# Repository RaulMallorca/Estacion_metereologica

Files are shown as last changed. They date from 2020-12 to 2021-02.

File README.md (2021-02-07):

# # Hoja de ruta - Estación metereológica con NodeMcu.

_Modesto proyecto para afianzar conocimientos adquiridos en varios ámbitos._
_Este proyecto está basado en la colaboración de todas esas personas que comparten desisteresadamente sus trabajos. Está modificado para conseguir lo deseado._
_En algun lugar de este readme.me intentaré añadir todos los enlaces, gracias a los cuales, espero conseguir realizar la estación meteorológica._

Descripción del proyecto
_La estación medirá la temperatura, humedad, señal RSSI wifi, tanto interior como exterior, presión, rayos UV-A y UV-B, velocidad y dirección del viento y lluvia. Los datos se visualizarán en un dashboard creado 
en la plataforma de gestión de datos Thinger.io. Además con otro NodeMCU donde se obtendrán los datos de temperatura, humedad y señal RSSI wifi, interior, se mostrarán en una pantalla Nextion de 7".

## Material necesario 🚀

_El material utilizado se puede modificar pero se tendrá que hacer lo propio con el código._

**NodeMCU**

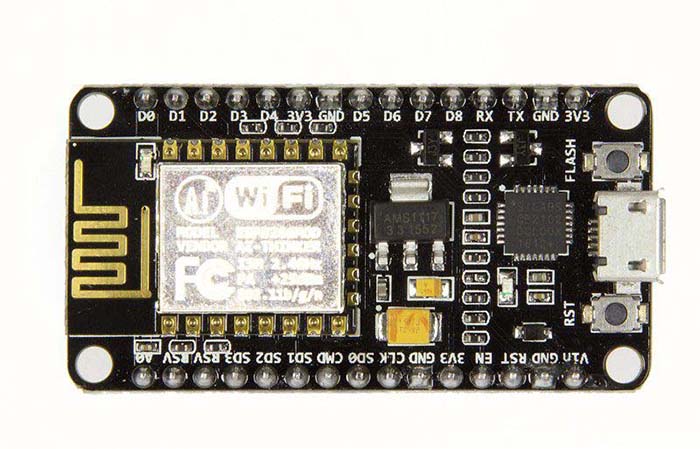
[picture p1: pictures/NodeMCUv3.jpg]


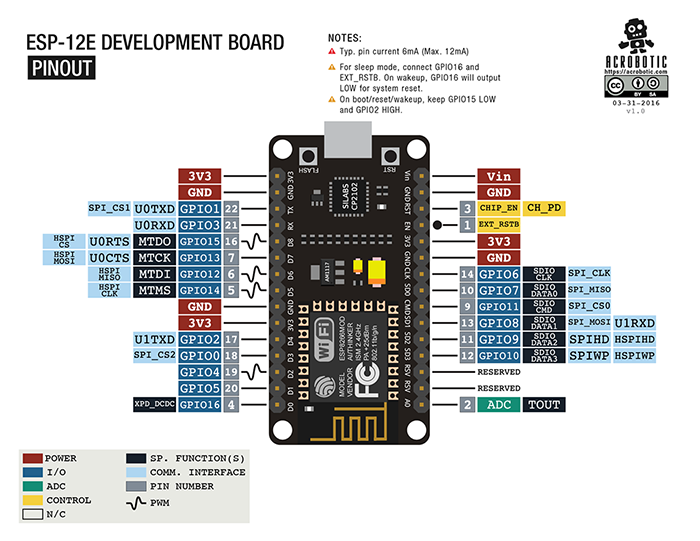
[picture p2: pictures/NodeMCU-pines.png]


Poco que añadir a esta placa. http://nodemcu.com/index_en.html. Basada en el ESP8266.

Tiene un puerto micro USB

Conversor Serie-USB, el CH340G

Tiene pines, un LED y dos botones, uno para reinicio y otro para flasheo.

Se alimenta a 3,3V.

3 salidas de 3,3V

1 de 5 (Solo da 5V si en las otras no hay nada conectado)

La v3 que yo tengo, solo se puede usar a 9600 bps Al establecer conexión mediante el puerto serie, *Serial.begin (9600);*

Necesataremos 2 placas.

**SENSORES**

**BME280** 	

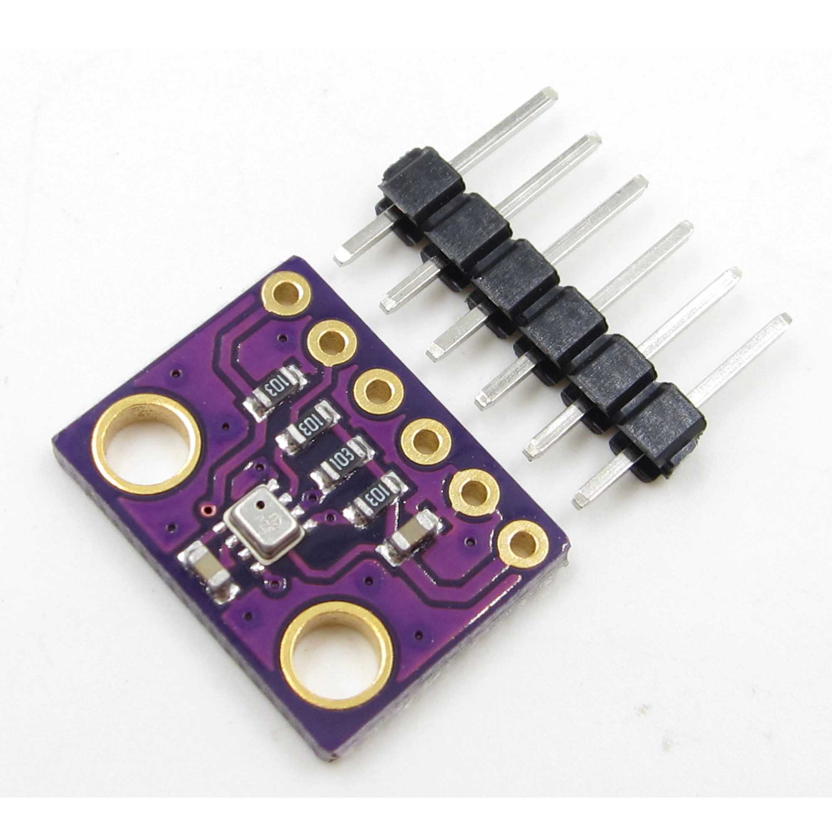
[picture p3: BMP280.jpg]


• Temperatura (rango de -40 a + 85 °C, precisión ±1 °C y resolución 0,01 °C)

• Humedad (a 100%, con una precisión de ±3% Pa y una resolución de 0.008%)
            
• Presión (300-1100 hPa, precisión de ±1 Pa, y resolución de 0,18 Pa)         

• Current consumption 
 -1.8 μA a 1Hz - Humedad y temperatura
 - 2.8 μA a 1Hz - Presión y temperatura
 - 3.6 μA a 1Hz - Humedad, presión y temperatura
 - 0.1 μA in sleep mode
- V 3,3V

Necestaremos 2 sensores.

**BH1750**

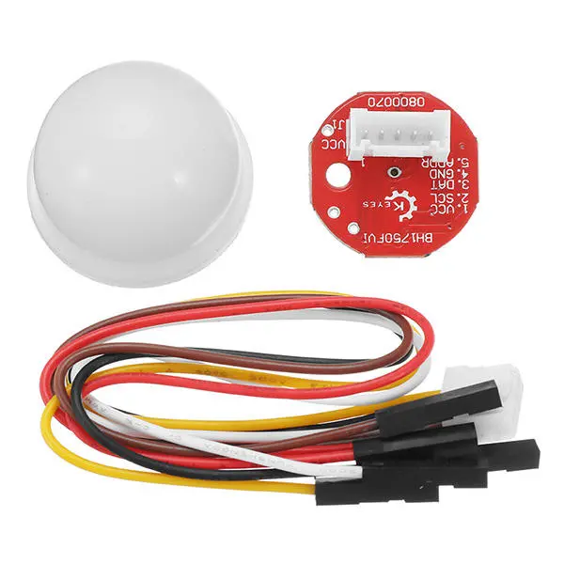
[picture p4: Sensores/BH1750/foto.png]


Las características del sensor **BH1750** son las siguientes:
- Interfaz I2C con dos posibles direcciones. 0x5C y 0x23 (por defecto).
- Representación del espectro apróximadamente a la del ojo humano.
- Alta resolución, (1 - 65535 lx) 
- Baja dependencia al tipo de luz. (Incandescente, fluorescente, halógena, LED, sol)
- Resutado de medición ajustable teniendo en cuenta el "cascarón" que cubre el sensor. (Es posible detectar un mínimo de 0,11 lx, un máximo de 100000 lx utilizando esta función.)
- Baja influencia de luz infrarroja.

Especificaciones:
- Voltaje
  - mín 2,4V
  - max 3,6V
- Resolución 4lux, 1lux, 0,5lux. Usando la resolución de 1lux permite distinguir iluminaciones por debajo de los 10lux (luz crepúscular) Para 1 lux y 4 lux se usan los 16bits de datos, llegando a los 65535 lux (día soleado sin luz directa) En el modo 0,5 lux usa 15 bits y puede representar un valor máximo de 32767 lux (exterior sin luz directa) [Fuente](http://polaridad.es/bh1750-luz-sensor-iluminacion-ambiental-i2c-medida-luminosidad-medicion/)
- Consumo
  - mín 0,01 μA
  - max 190 μA

Necestaremos 1 sensor.

**SENSOR LLUVIA YL-83**

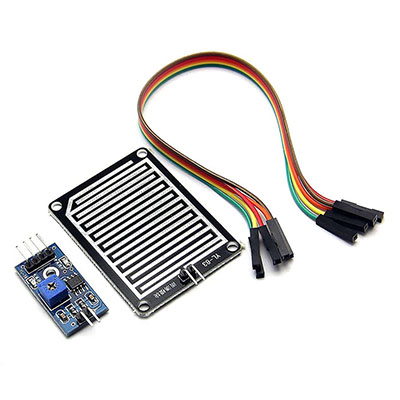
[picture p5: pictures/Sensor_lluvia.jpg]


Output

• Maximum voltage 15 V

• Maximum current 50 mA

Input

• Control to switch heater OFF

Open circuit input enables the heater.

Connection to GND disables the heater.

• Contact rating min. 15 V, 2 mA

• Supply voltage 12 VDC ± 10 %

• Supply current

• Typical less than 150mA

• Maximum 260mA

• Supply voltage 3,3 VDC (I'm not sure of this counting)

• Supply current

• Typical less than 41mA

• Maximum 70mA

**VELOCIDAD DEL VIENTO**

**UV ML8511 y ADC ADS1115**

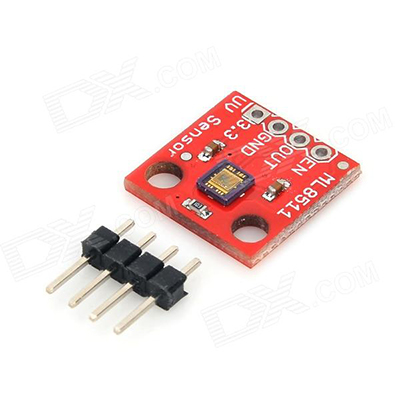
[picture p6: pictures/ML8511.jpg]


• Longitud de onda: 280-390nm

• Current consumption  300 μA 
                      standby current 0.1 μA

El sensor **UV ML8511** al necesitar dos pines analógicos y el NodeMCU disponer solo de 1, necesitamos un multiplexor/desmultiplexor, como el ADS1115.

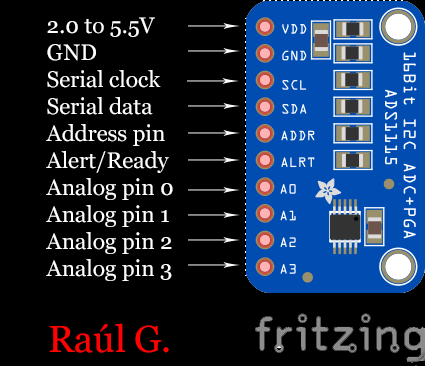
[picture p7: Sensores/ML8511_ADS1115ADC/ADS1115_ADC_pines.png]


Según el ejemplo de Sparkfun, las conversiones analógicas a digitales dependen completamente del voltaje. Si alimentamos el sensor mediante la placa y esta a través de un USB, el voltaje puede variar de 5,25V a 4,75V. Por eso utilizaremos los 3,3V del NodeMCU. El pin marcado con **3,3V** del sensor irá conectado a **3,3V** y al **pin A1** del ADS1115. El pin **Out** irá al pin analógico **A0** del ADS1115. El **EN** ira a **3,3V** también. En el apartado de sensores/Ml8511...puedes ver el esquemático.

**Pantalla Nextion NX8048P070-011C-Y**

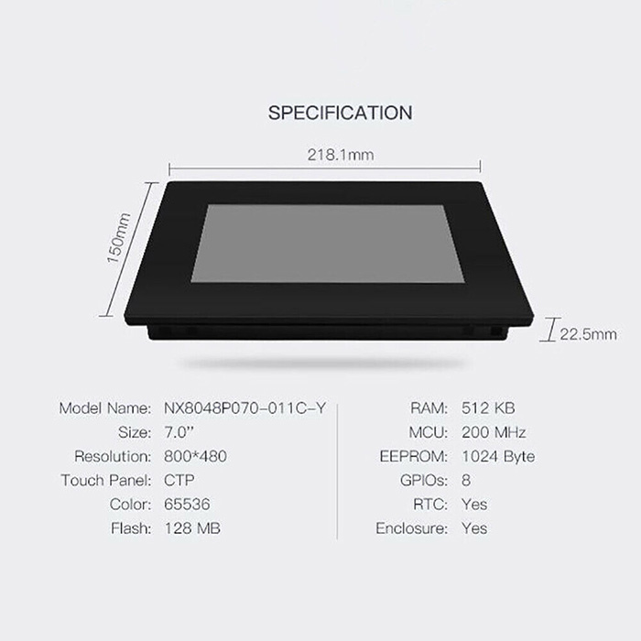
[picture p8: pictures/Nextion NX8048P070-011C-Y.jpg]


Pantalla táctil TFT capacitiva colores reales RGB 65K.

Memoria Flash de 128MB para código de aplicación de usuario y datos.

EEPROM: 1024 bytes

RAM: 512 KB

Interfaz: interfaz serie XH2.54 4 pin TTL

Voltaje de entrada: 4,7-7 V (estándar de 5 V)

Corriente de entrada: 750mA (brillo máximo), 170mA (modo de suspensión). Potencia recomendada: 5V mínimo 1A

Altavoz: 0,5 vatios de capacidad nominal, impedancia de 16 Ω

Tamaño de la pantalla: 7,0 pulgadas

Resolución de la pantalla: 800x480 píxeles

Brillo de la pantalla: 300 cd/m ^ 2,(0 ~ 300 nit, el intervalo de ajuste es 1%)

Ranura para tarjeta micro SD integrada, FAT32. Adecuado para una tarjeta SD de hasta 32GB

Fuente de alimentación Micro USB macho.

Visual: 154,08mm(L) x 85,92mm(W)

Dimensiones: 218,1x150x22,5mm.

**Cajas**

Una para guardar los sensores y el NodeMCU exterior.

Una para guardar los sensores y el NodeMCU interior.

Una para la pantalla Nextion

### Pre-requisitos 📋

_Software, drivers y extras a instalar_

Un IDE para crear el skecht. Yo he usado el IDE de Arduino, concretamente el 1.8.13. https://www.arduino.cc/en/pmwiki.php?n=main/software.

Drivers para el conversor Serie-USB CH340G. Lo puedes encontrar fácilmente por internet.

### Instalación 🔧

_Una serie de ejemplos paso a paso que te dice lo que debes ejecutar para tener un entorno de desarrollo ejecutandose_

_Dí cómo será ese paso_

```
Da un ejemplo
```

_Y repite_

```
hasta finalizar
```

_Finaliza con un ejemplo de cómo obtener datos del sistema o como usarlos para una pequeña demo_

## Ejecutando las pruebas ⚙️

_Explica como ejecutar las pruebas automatizadas para este sistema_

### Analice las pruebas end-to-end 🔩

_Explica que verifican estas pruebas y por qué_

```
Da un ejemplo
```

### Y las pruebas de estilo de codificación ⌨️

_Explica que verifican estas pruebas y por qué_
```
Da un ejemplo
```

## Despliegue 📦

_Agrega notas adicionales sobre como hacer deploy_

## Construido con 🛠️

_Menciona las herramientas que utilizaste para crear tu proyecto_

* [Dropwizard](http://www.dropwizard.io/1.0.2/docs/) - El framework web usado
* [Maven](https://maven.apache.org/) - Manejador de dependencias
* [ROME](https://rometools.github.io/rome/) - Usado para generar RSS

## Contribuyendo 🖇️

Por favor lee el [CONTRIBUTING.md](https://gist.github.com/villanuevand/xxxxxx) para detalles de nuestro código de conducta, y el proceso para enviarnos pull requests.

## Wiki 📖

Puedes encontrar mucho más de cómo utilizar este proyecto en nuestra [Wiki](https://github.com/tu/proyecto/wiki)

## Versionado 📌

Usamos [SemVer](http://semver.org/) para el versionado. Para todas las versiones disponibles, mira los [tags en este repositorio](https://github.com/tu/proyecto/tags).

## Autores ✒️

_Menciona a todos aquellos que ayudaron a levantar el proyecto desde sus inicios_

* **Andrés Villanueva** - *Trabajo Inicial* - [villanuevand](https://github.com/villanuevand)
* **Fulanito Detal** - *Documentación* - [fulanitodetal](#fulanito-de-tal)

También puedes mirar la lista de todos los [contribuyentes](https://github.com/your/project/contributors) quíenes han participado en este proyecto. 

## Licencia 📄

Este proyecto está bajo la Licencia (Tu Licencia) - mira el archivo [LICENSE.md](LICENSE.md) para detalles

## Expresiones de Gratitud 🎁

* Al usuario [Ega] https://community.thinger.io/u/ega, de la comunidad Thinger.io . Por la ayuda prestada para conseguir obtener los datos desde Thinger.io🤝 
* A Luis de [Programarfacil.com] http://programarfacil.com. Detonante para decidirme a realizar mi propia estación.🙌
* [esploradores.com] http://esploradores.com 
* etc.

---
⌨️ con ❤️ por [Villanuevand](https://github.com/Villanuevand) 😊

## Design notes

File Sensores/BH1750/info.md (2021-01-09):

Las características del sensor **BH1750** son las siguientes:
- Interfaz I2C con dos posibles direcciones. 0x5C y 0x23 (por defecto).
- Representación del espectro apróximadamente a la del ojo humano.
- Alta resolución, (1 - 65535 lx) 
```
lightMeter.begin(BH1750::ONE_TIME_HIGH_RES_MODE);
```
En este modo el sensor mide una vez y automaticamente entra en el modo apagado.
O:
```
lightMeter.begin(BH1750::CONTINUOUS_HIGH_RES_MODE);
```
En este modo el sensor mide continuamente.

- Baja dependencia al tipo de luz. (Incandescente, fluorescente, halógena, LED, sol)
- Resutado de medición ajustable teniendo en cuenta el "cascarón" que cubre el sensor. (Es posible detectar un mínimo de 0,11 lx, un máximo de 100000 lx utilizando esta función.)
- ±20% de error
- Baja influencia de luz infrarroja.

Especificaciones:
- Voltaje
  - mín 2,4V
  - max 3,6V
- Resolución 4lux, 1lux, 0,5lux. Usando la resolución de 1lux permite distinguir iluminaciones por debajo de los 10lux (luz crepúscular) Para 1 lux y 4 lux se usan los 16bits de datos, llegando a los 65535 lux (día soleado sin luz directa) En el modo 0,5 lux usa 15 bits y puede representar un valor máximo de 32767 lux (exterior sin luz directa) [Fuente](http://polaridad.es/bh1750-luz-sensor-iluminacion-ambiental-i2c-medida-luminosidad-medicion/)
- Consumo
  - mín 0,01 μA
  - max 190 μA
  
Si queremos usar la dirección I2C 0x5C tenemos que conectar el pin ADDR a un voltaje mayor de 0,7V, por ejemplo al pin de 3,3V que alimenta al sensor. Si el voltaje del pin ADDR es menor a 0,7V, la dirección será 0x23.

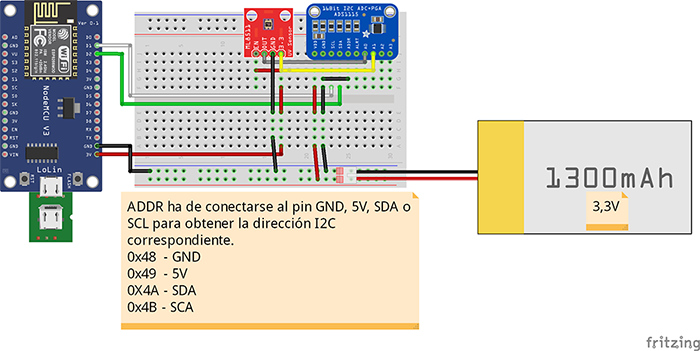
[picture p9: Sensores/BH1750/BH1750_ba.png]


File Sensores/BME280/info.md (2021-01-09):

Las especificciones del sensor **BME280**, no confundirlo con el **BMP280** que no mide la humedad, son las siguientes:

- Conexión I2C
- Resolución humedad 0.008 %RH
- Tolerancia precisión absoluta ± 3 %RH
  
- Resolución presión 0.18 Pa 
- Rango de medición 300 a 1100 hPa
  - Tolerancia precisión absoluta 
    - 300 ... 1100hPa y -20 ºC ...0 ºC ±1.7 hPa
    - 300 ... 1100hPa y 0 ºC ... 65 ºC ±1 hPa
    - 300 ... 1100hPa y 25 ºC... 40 ºC ±1.5 hPa
  
- Resolución temperatura 0.01 ºC
- Tolerancia precisión absoluta 
    - 0 ºC ... 65 ºC ± 1ºC
    - -20 ºC ... 0 ºC ±1.25 ºC
    - -40 ºC ... -20 ºC ±1.5 ºC

El resultado obtenido es en Pascales (Pa). 
- **Equivalencias**
  - 1 bares = 100000 Pa
  - 1 mbar = 100 Pa
  - 1 hPa = 100 Pa
  - 1 mmHg = 133,32 Pa
  - 1 hPa = 0.75 mmHg

En el código la unidad está combertida a hPa o mbar de la siguiente manera:

> **_(bme.readPressure() / 100.0F);_**

Un pequeño problema que me surgió a la hora de conseguir comunicación con el módulo del sensor BME280 fue el no haber tenido en cuenta que venía sin el puente de unión para elegir la dirección I2C. No conseguí encontrar referencias sobre las direcciones hasta que visité la magnífica página de [patagoniatec.com](http://patagoniatec.com) donde detallaban este tema en concreto.

Si hacéis la soldadura, no habrá mayor problema. Como a día de hoy, 24/12/2020 sigo esperando más sensores que usarán el protocolo I2C, no he querido hacer el puente para después que coincidiera alguna dirección con otro sensor y tuviera que desoldar. 

La manera rápida y limpia de corregir esto es mediante programación.

Cuando iniciamos el sensor en void setup() con

>**_bme.begin();_**

Dentro del paréntesis debemos indicarle la dirección elegida, 0x76 o 0x77.

>**_bme.begin(0x76);_**

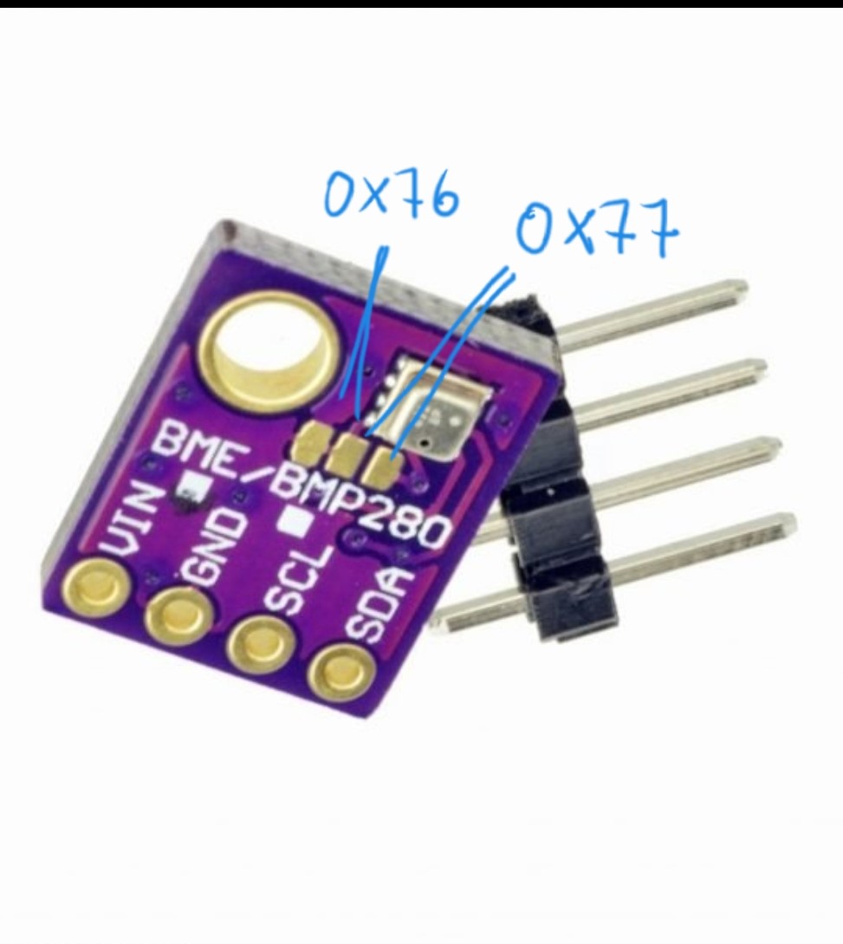
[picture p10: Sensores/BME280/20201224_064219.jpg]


La conexión con el nodeMCU no tiene complicación. Unimos el pin D1 del nodeMCU con el pin SCL y el pin D2 con el pin SDA del módulo. Compartimos masas y alimentamos el sensor con 3,3V o 5V, dependiendo si hemos comprado un módulo con regulador de tensión o sin él, en mi caso, compré ambos y terminé montando el de 3,3V. La placa del nodeMCU la alimentamos desde el USB.

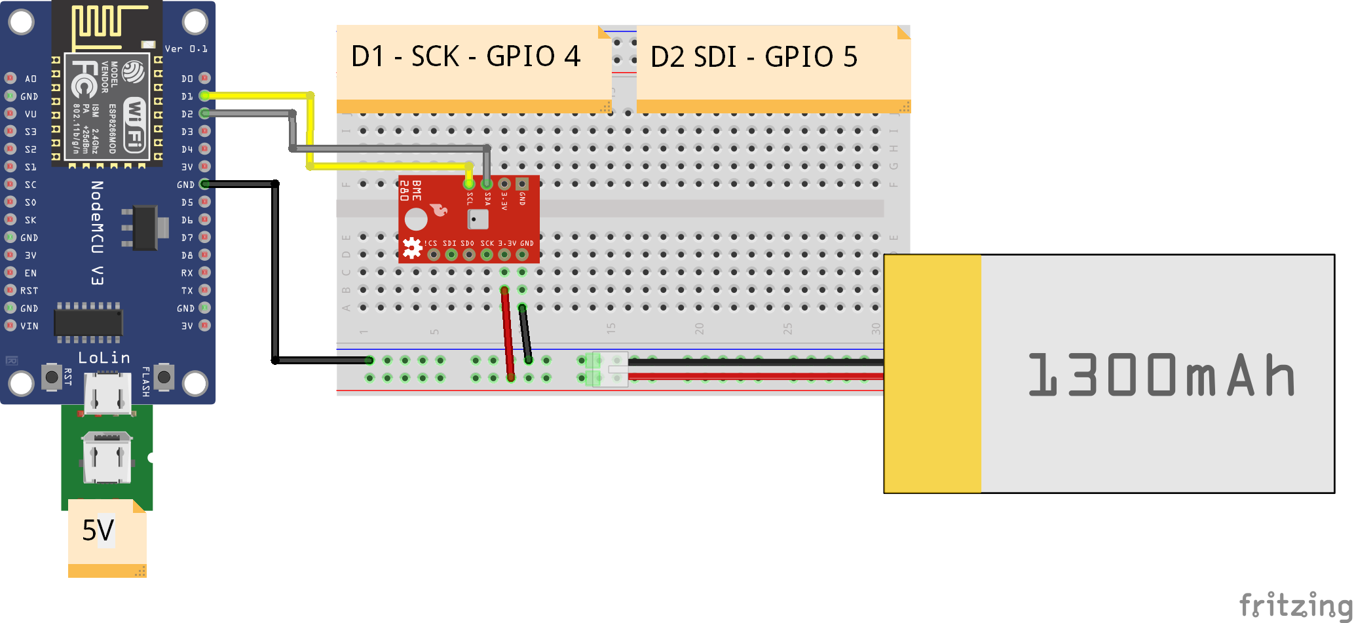
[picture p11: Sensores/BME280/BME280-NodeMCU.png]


La batería del esquema es orientativa, para diferenciar la alimentación del módulo del sensor de la placa donde está alojado el 8266.

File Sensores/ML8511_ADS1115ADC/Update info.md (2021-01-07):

Las especificaciones del sensor **ML8511 UV** son las siguientes:

- Fotodiodo sensible a la radiación UV-A y UV-B.
- Salida analógica.

- Voltaje  
  - min 2,7V
  - max 3,6V

- Consumo
  - Standby 0,1µA
  - Bajo consumo 300µA
  
[Fuente1](https://learn.sparkfun.com/tutorials/ml8511-uv-sensor-hookup-guide/all)
  
Las especificiaciones del ADC ADS1115 son las siguientes:

- Interfaz I2C, seleccionable mediante pin. 4 direcciones, 0x48, 0x49, 0x4A y 0x4B. [Fuente2](https://programarfacil.com/blog/arduino-blog/ads1115-convertidor-analogico-digital-adc-arduino-esp8266/)
- Resolución de 16bits.
- 4 pines analógicos.
- Amplificador de ganancia programable, **PGA**, mayor precisión y fiabilidad a través del código.
- Voltaje
  - min 2V
  - max 5,5V
- Consumo
  - Modo single-shot auto apagado.
  - Continuo 150µA
  
- VDD a GND –0,3V to +5,5 V
- Corriente entrada analógica 100mA momentary 
- Corriente de entrada analógica 10mA continuous

- **Voltaje entrada analógica  a GND –0,3V a VDD + 0,3V**
- SDA, SCL, ADDR, ALERT/RDY voltaje a GND –0,5V a +5,5V

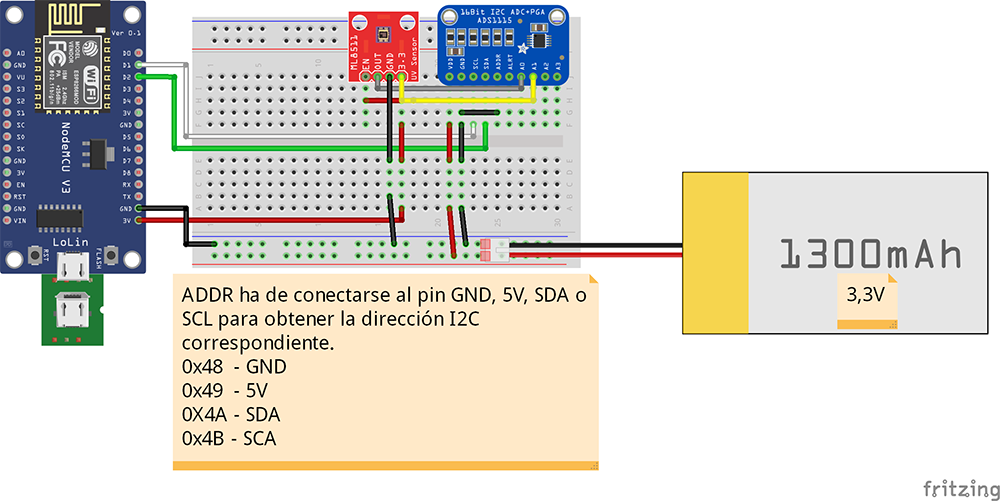
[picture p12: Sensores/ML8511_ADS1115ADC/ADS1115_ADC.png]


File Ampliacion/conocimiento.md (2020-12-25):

# **Meteorología**

- **Los anticiclones** son zonas de altas presiones, normalmente mayor de 1023,25 hPa o mbar, en las que el aire frío desciende. Se asocia a buen tiempo. En el hemisferio norte
este aire frío gira en sentido horario. Lo contrario ocurre en el hemisferio sur.

- **Las borrascas o ciclones** son zonas de bajas presiones, por debajo de 1023,25 hPa o mbar, en las que el aire caliente y húmedo asciende, este crea nubes y hay probabilidad 
de lluvia. Se asocia a inestabilidad y mal tiempo. En el hemisferio norte el aire caliente y húmedo que sube gira en sentido contrario a las agujas del reloj. Lo contrario ocurre
en el hemisferio sur.

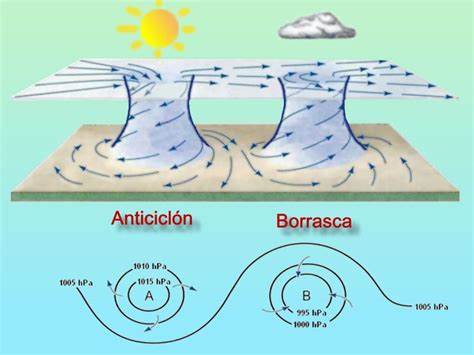
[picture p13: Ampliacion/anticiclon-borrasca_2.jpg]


> _Cuando el aire está frío, se contrae, aumenta la densidad y, por lo tanto, desciende, haciendo aumentar la presión y provocando estabilidad barométrica o anticiclónica: se 
forma así una zona de calmas, es decir, sin vientos, ya que el aire frío y pesado desciende lentamente en sentido circular y comienza a girar casi imperceptiblemente en sentido 
horario en el hemisferio norte y antihorario en el hemisferio sur. Se forma, entonces, un anticiclón. Cuando el aire está caliente, asciende, haciendo bajar la presión y 
provocando inestabilidad. Se forma así un ciclón o borrasca.

> _Además, el aire frío y el cálido no se mezclan de manera inmediata, debido a la diferencia de densidades; y cuando se encuentran en superficie, el aire frío empuja hacia arriba 
al aire caliente provocando un descenso de la presión e inestabilidad, por causas dinámicas. Se forma entonces un ciclón, o borrasca dinámica. Esta zona de contacto es la que se 
conoce como frente._

[Fuente](https://es.wikipedia.org/wiki/Presi%C3%B3n_atmosf%C3%A9rica)

La presión atmosférica disminuye a razón de 1,33mmbar por cada 10 metros de altura en zonas próximas al mar. La estación se encuentra a una altura aproximada de 130 metros según
la [topographic-map.com](https://es-es.topographic-map.com/) 

Sabiendo la altura podemos usar cualquier calculadora online para hayar la presión atmosférica.

[Calculadora online](https://www.herramientasingenieria.com/onlinecalc/spa/altitud/altitud.html)

# **INCOMPLETO**
En este caso una presión normal debería ser 997.74 mbar

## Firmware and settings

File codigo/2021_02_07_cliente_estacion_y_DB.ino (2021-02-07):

/*Cliente estación metereológica con pantalla Nextion. Ver los datos de Thinger.io por el monitor serie

  http://api.thinger.io/v1/users/EstacionMeteo/buckets/DATOS_ESTACION/data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
   ese link no debería caducar
 * */

#include <ESP8266WiFi.h>  //Librería de conexión WiFi del módulo ESP8266
#include <ESP8266HTTPClient.h>  //Librería de conexión cliente del módulo ESP8266
#include <ThingerESP8266.h> //Librería de la plataforma thinger.io
#include <Wire.h>              // Librería para el sensor BME280
#include <SPI.h>               // Librería para el sensor BME280
#include <Adafruit_Sensor.h>  // Librería para el sensor BME280
#include <Adafruit_BME280.h>  // Librería para el sensor BME280
#include <ArduinoOTA.h> //Librería necesaria para el uso de OTA
#include "ESP8266_Utils_OTA.hpp"  //Configuración para uso de OTA

//Datos Thinger.io
#define USERNAME "EstacionMeteo"
#define DEVICE_ID "Servidor_Meteo"
#define DEVICE_CREDENTIAL "A+aKTL!K2!Dv"
ThingerESP8266 thing(USERNAME, DEVICE_ID, DEVICE_CREDENTIAL);

#define _DEBUG_

//Value httpRequest_THINGERio
String lastBucketValue;

/*-----------------VARIABLES DE LOS DATOS OBTENIDOS DESDE THINGER.IO--------------------*/
float humeout;
float tempout;
float lumi;
float altitud;
int RSSIout;
float presion;

Adafruit_BME280 bme; // BME280 conectado por I2C

// Timer
unsigned long ultimaConsulta = 0;
unsigned long tiempoConsulta = 120000;

/*---------IMPORTANTE no poner la "s" en "http" ------------------*/
String link = "http://api.thinger.io/v1/users/EstacionMeteo/buckets/DATOS_ESTACION/data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";

/*-----------Parámetros Wifi-----------*/
const char* ssid = "RedWifi"; // Nuestro SSID (Nombre de la red)
const char* password = "KirguisT@N2035"; // Nuestra contraseña
const char* host = "192.168.1.59";  // IP servidor
const int   port = 80;            // Puerto servidor
//const int   tiempo_Consulta = 60000;        // Tiempo hasta conexión Wifi.

/*----------FUNCIÓN PARA LA CONEXIÓN A LA RED WIFI-----------*/
void configWifi () {
 // IPAddress staticIP (192, 168, 1, 100); //Indicamos una IP fija
 // IPAddress gateway (192, 168, 1, 1); //Puerta de enlace de nuestra conexión
 // IPAddress subnet (255, 255, 255, 0); //Máscara de subred.

  Serial.print ("Conectando con ");
  Serial.println (ssid);

  //Wifi conexion
  WiFi.mode (WIFI_STA); //Configuración en modo cliente
  WiFi.begin (ssid, password); //Iniciamos la conexión WiFi
  //WiFi.config (staticIP, gateway, subnet);  //Configuramos la conexión
  
  while (WiFi.status() != WL_CONNECTED) { //Mientras no estemos conectados
    delay(500); //Cada medio segundo
    Serial.print (".");   //Imprimimos un "." por el monitor serie.
  }
  Serial.println ("");
  Serial.print ("Conectado a la red ");
  Serial.println (ssid);
  Serial.println("IP address: ");
  Serial.println(WiFi.localIP());
}

String httpRequest_THINGERio (String link) {
  String payload;
  if (WiFi.status() == WL_CONNECTED) {  //Check Wifi connection status
    HTTPClient http;  //Declare an object of class HTTPClient
    http.begin (link);  //Specify request destinatino
    int httpCode = http.GET();

    Serial.print ("Código HTTP: ");
    Serial.println (httpCode);

    if (httpCode > 0 ) {  //Check the returning code. Thinger.io codes. 200 = ok, 401 = No authorized, 404 = No found.
      payload = http.getString(); //Get the request response payload
      //Serial.println ("El valor de payload es "); //comentar una vez comprobado que interpreta bien los datos
      //Serial.println (payload); //comentar una vez comprobado que interpreta bien los datos
    } else if (httpCode < 0) {  //If the returning code is less than 0, there is an error, them
      Serial.println ("ERROR payload");
    }
    http.end(); //Close connection
  }
  return payload;
}

float varExtract (String varToExtract, String payload) {
  int Start = payload.indexOf (varToExtract) + varToExtract.length() + 2; //Indicamos el inicio donde se encuentra el valor del sensor.
  /*----------https://www.arduino.cc/reference/en/language/variables/data-types/string/functions/length/ ----------------*/
  //Serial.println("El valor de Start es: "); //comentar una vez comprobado que interpreta bien los datos
  //Serial.println (Start);   //comentar una vez comprobado que interpreta bien los datos
  int End = payload.indexOf (",", Start); //Indicamos donde acaba nuestro  valor del sensor
  //Serial.println("El valor de End es: "); //comentar una vez comprobado que interpreta bien los datos
  //Serial.println (End); //comentar una vez comprobado que interpreta bien los datos
  if (End < 0) {  //Last variable doesn't have "," at the end, have a "]"
    End = payload.indexOf ("}");
  }
  String stringVar = payload.substring (Start, End);  //Obtiene el valor con todos los decimales, 16.7784938493202 p.e.
  //Serial.println("El valor de stringVar es :"); //comentar una vez comprobado que interpreta bien los datos
  //Serial.println(stringVar);  //comentar una vez comprobado que interpreta bien los datos
  float var = stringVar.toFloat();  //Nos quedamos con solo 2 decimales.
  //Serial.println("El valor de var es: "); //comentar una vez comprobado que interpreta bien los datos
  //Serial.println(var);  //comentar una vez comprobado que interpreta bien los datos
  return var;
}

void timer () {
  if (millis() < ultimaConsulta) {  //Comprobar si se ha dado la vuelta
    ultimaConsulta = millis();  //Asignar un nuevo valor
  }
  if ((millis() - ultimaConsulta) > tiempoConsulta) {
    ultimaConsulta = millis();  //Marca de tiempo
    lastBucketValue = httpRequest_THINGERio (link);

    /*---------desComentar una vez comprobado que interpreta bien los datos---------*/
    tempout = varExtract ("Temperatura", lastBucketValue);
    Serial.print ("Temperatura exterior: ");
    Serial.print (tempout);
    Serial.println ("ºC");
    /*----------------------------FIN COMENTAR----------------------------*/

    /*---------desComentar una vez comprobado que interpreta bien los datos---------*/
    humeout = varExtract ("Humedad", lastBucketValue);
    Serial.print ("Humedad exterior: ");
    Serial.print (humeout);
    Serial.println ("%");
    /*----------------------------FIN COMENTAR----------------------------*/

    /*---------desComentar una vez comprobado que interpreta bien los datos---------*/
    altitud = varExtract ("Altitud aproximada", lastBucketValue);
    Serial.print ("Altitud aproximada: ");
    Serial.print (altitud);
    Serial.println ("m");
    /*----------------------------FIN COMENTAR----------------------------*/

    /*---------desComentar una vez comprobado que interpreta bien los datos---------*/
    RSSIout = varExtract ("RSSI out", lastBucketValue);
    Serial.print ("Señal RSSI out: ");
    Serial.print (RSSIout);
    Serial.println ("dBm");
    /*----------------------------FIN COMENTAR----------------------------*/

    /*---------desComentar una vez comprobado que interpreta bien los datos---------*/
    presion = varExtract ("Presión", lastBucketValue);
    Serial.print ("Presión: ");
    Serial.print (presion);
    Serial.println ("hPa");
    /*----------------------------FIN COMENTAR----------------------------*/

    /*------desComentar una vez comprobado que interpreta bien los datos------*/
    lumi = varExtract ("Luminosidad", lastBucketValue);
    Serial.print ("Luminosidad: ");
    Serial.print (lumi);
    Serial.println ("lux");
    /*----------------------------FIN COMENTAR----------------------------*/
    leer_Sensores_Local ();

    //Envío datos BD
     WiFiClient client;

    if (!client.connect(host, port)) {
      Serial.println("Fallo al conectar");
      return;
    }
    
    /*-------DECLARACIÓN DE LAS VARIABLES------------*/
  float tempint = bme.readTemperature();
  float humeint = bme.readHumidity();
  int rssiInt = WiFi.RSSI();
  
    String url = "/servidor_estacion/index.php?"; //Construimos la URL datos_Estacion/index.php?temp=[La tª del sensor]&hume=[la humedad del sensor]
  url += "&tempint=";
  url += tempint; //mostrará la temperatura después de temp=
  url += "&humeint="; //añadimos lo que falta a la URl(ha de coincidir con las variables creadas en el archivo php)
  url += humeint; //mostrará la humedad después de &hum=
  url += "&rssiInt=";
  url += rssiInt;
  url += "&tempout=";
  url += tempout;
  url += "&humeout="; //añadimos lo que falta a la URl(ha de coincidir con las variables creadas en el archivo php)
  url += humeout;
  url += "&presion="; //mostrará la presión después de &presion (ha de coincidir con las variables creadas en el archivo php)
  url += presion; //mostrará la presión después
  url += "&lumi=";
  url += lumi;
    
    // Enviamos petición al servidor
    client.print(String("GET ") + url + " HTTP/1.1\r\n" +
                 "Host: " + host + "\r\n" +
                 "Connection: close\r\n\r\n");
    unsigned long timeout = millis();
    while (client.available() == 0) {
      if (millis() - timeout > 5000) {
        Serial.println(">>> Client Timeout !");
        client.stop();
        return;
      }
    }

    // Leemos la respuesta del servidor
    while (client.available()) {
      String line = client.readStringUntil('\r');
      Serial.print(line);
    }
  }
}

/*---FUNCIÓN PARA EL ENVÍO DE LAS LECTURAS DE LOS SENSORES A LA BASE DE DATOS---*/
void httprequest_DATA_BASE () {
  /*-------DECLARACIÓN DE LAS VARIABLES------------*/
  float tempint = bme.readTemperature();
  float humeint = bme.readHumidity();
  int rssiInt = WiFi.RSSI();

  WiFiClient client;

  if (!client.connect(host, port)) {
    Serial.println("Fallo al conectar");
    return;
  }
  /*---------------------------------Así se muestra en el navegador---------------------------------*/
  /* //http://192.168.1.59/servidor_estacion/index.php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 */

  String url = "/servidor_estacion/index.php?"; //Construimos la URL datos_Estacion/index.php?temp=[La tª del sensor]&hume=[la humedad del sensor]
  url += "&tempint=";
  url += tempint; //mostrará la temperatura después de temp=
  url += "&humeint="; //añadimos lo que falta a la URl(ha de coincidir con las variables creadas en el archivo php)
  url += humeint; //mostrará la humedad después de &hum=
  url += "&rssiInt=";
  url += rssiInt;
  url += "&tempout=";
  url += tempout;
  url += "&humeout=";
  url += humeout;
  url += "&presion="; //mostrará la presión después de &presion (ha de coincidir con las variables creadas en el archivo php)
  url += presion; //mostrará la presión después
  url += "&lumi=";
  url += lumi;

  // Enviamos petición al servidor
  client.print(String("GET ") + url + " HTTP/1.1\r\n" +
               "Host: " + host + "\r\n" +
               "Connection: close\r\n\r\n");
  unsigned long timeout = millis();
  while (client.available() == 0) {
    if (millis() - timeout > 5000) {
      Serial.println(">>> Client Timeout !");
      client.stop();
      return;
    }
  }

  // Leemos la respuesta del servidor
  while (client.available()) {
    String line = client.readStringUntil('\r');
    Serial.print(line);
  }
}

void leer_Sensores_Local () {
  //Mostrar los datos de presión, temperatura, altitud y humedad por el monitor serie.
  Serial.print ("Temperatura local: ");
  Serial.print (bme.readTemperature());
  Serial.println (" ºC");
  Serial.print ("Humedad local: ");
  Serial.print (bme.readHumidity());
  Serial.println ("%");
  Serial.print ("Temp out: ");
  Serial.println (tempout);
  Serial.print ("Humedad out: ");
  Serial.println (humeout);
  Serial.print ("RSSI local: ");
  Serial.print (WiFi.RSSI());
  Serial.println ("dBm");
}

void setup() {
  Serial.begin (9600);  //Iniciamos el monitor serie
  configWifi(); //Coenctamos a la red Wifi.
  thing.add_wifi (ssid, password);  //Conectamos a Thinger.IO

  unsigned status;
  // default settings
  status = bme.begin(0x76);
  // You can also pass in a Wire library object like &Wire2
  // status = bme.begin(0x76, &Wire2)
  if (!status) {
    Serial.println("¡¡No se encuentra el sensor BME280, comprueba conexiones, dirección y la ID del sensor!!");
    Serial.print("SensorID was: 0x"); Serial.println(bme.sensorID(), 16);
    Serial.print("        ID of 0xFF probablemente la dirección está mal o el sensor es un BMP 180 o BMP 085\n");
    Serial.print("   ID of 0x56-0x58 representa un BMP 280,\n");
    Serial.print("        ID of 0x60 representa un BME 280.\n");
    Serial.print("        ID of 0x61 representa un BME 680.\n");
    while (1) delay(10);
  }

  InitOTA();  //Ajustes como puerto, password, etc (ESP8266_Utils_OTA.hpp)
}

void loop() {

  timer();
  ArduinoOTA.handle();
}

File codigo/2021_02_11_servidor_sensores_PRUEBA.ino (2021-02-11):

/*
  Lectura de datos de temperatura, humedad, altura aproximada y presión con sensor BME280. Luminosidad con BH1750, Anemómetro, veleta y pluviómetro con Argent Data Systems,
  índice UV con ML8511 con la placa NodeMCU. Monitorización en la plataforma www.thinger.io.
  
  El pluviómetro muestra la precipitación caída durante 1h y durante 24h. Después se reinician los dos contadores.
 *Necesita una resistencia de 10kOhm pull-up (Pin V, pin D6 y pin+ del pluviómetro.

  El anemómetro y la veleta también usan una resistencia cada uno de 10kOhm pull-up (Pin V, pines correspondientes y pin+ de cada uno de los sensores).
  
  Envío de email según declaremos en IFTTT
  
  Código parcial de:
  Dani No www.esploradores.com (Thinger.IO)
  https://www.aeq-web.com/ (Anemómetro)
  Code wind vane Hans Huth and licensed under Creative Commons (Veleta)
  RimvydasP, https://www.instructables.com/NodeMCU-Wireless-Weather-Station/  (Pluviómetro)
  
*/

/*/////////////////////////////////////////////////////////////////////////////////\\\\\\\\\\\\\\\\\\\\\\\\\\\\\\\\\\\\\\\\\\\\\\\\\\\\\\\\\\\\\\\\\\\\\\\\\\\\\\\\
//////////////////////////////////////////////////////////////////////////===== Librerías =====\\\\\\\\\\\\\\\\\\\\\\\\\\\\\\\\\\\\\\\\\\\\\\\\\\\\\\\\\\\\\\\\\\\\
/////////////////////////////////////////////////////////////////////////////////\\\\\\\\\\\\\\\\\\\\\\\\\\\\\\\\\\\\\\\\\\\\\\\\\\\\\\\\\\\\\\\\\\\\\\\\\\\\\\\\*/

#include <ESP8266WiFi.h>       //Librería de conexión WiFi del módulo ESP8266
#include <ThingerESP8266.h>    //Librería de la plataforma thinger.io
#include <Wire.h>              // Librería para el sensor BME280, BH1750 y para el ADS1115
#include <Adafruit_ADS1015.h>  //Librería para el ADS1115
#include <SPI.h>               // Librería para el sensor BME280
#include <Adafruit_Sensor.h>  // Librería para el sensor BME280
#include <Adafruit_BME280.h>  // Librería para el sensor BME280
#include <ArduinoOTA.h>       //Librería necesaria para el uso de OTA
#include "ESP8266_Utils_OTA.hpp"  //Configuración para uso de OTA
#include <BH1750.h>           //Librería para el sensor BH1750.

/*/////////////////////////////////////////////////////////////////////////////////\\\\\\\\\\\\\\\\\\\\\\\\\\\\\\\\\\\\\\\\\\\\\\\\\\\\\\\\\\\\\\\\\\\\\\\\\\\\\\\\
////////////////////////////////////////////////////////////////////////===== Fin librerías =====\\\\\\\\\\\\\\\\\\\\\\\\\\\\\\\\\\\\\\\\\\\\\\\\\\\\\\\\\\\\\\\\\\
/////////////////////////////////////////////////////////////////////////////////\\\\\\\\\\\\\\\\\\\\\\\\\\\\\\\\\\\\\\\\\\\\\\\\\\\\\\\\\\\\\\\\\\\\\\\\\\\\\\\\*/

/*================================================================================================================================================================*/

//============================== Pines usados
const byte Anemometro = D5;     //Definimos el pin de interrupción para el anemómetro. GPIO 14
const byte RainSensorPin = D6;  //Pin Pluviómetro GPIO 12
#define direccion_Viento A0     //Pin Veleta

//============================== Definimos la presión a nivel del mar.
#define presion_Nivel_Mar_HPA (1013.25)  

/*/////////////////////////////////////////////////////////////////////////////////\\\\\\\\\\\\\\\\\\\\\\\\\\\\\\\\\\\\\\\\\\\\\\\\\\\\\\\\\\\\\\\\\\\\\\\\\\\\\\\\
//////////////////////////////////////////////////////////////////===== Parámetros de Thinger.io =====\\\\\\\\\\\\\\\\\\\\\\\\\\\\\\\\\\\\\\\\\\\\\\\\\\\\\\\\\\\\\
/////////////////////////////////////////////////////////////////////////////////\\\\\\\\\\\\\\\\\\\\\\\\\\\\\\\\\\\\\\\\\\\\\\\\\\\\\\\\\\\\\\\\\\\\\\\\\\\\\\\\*/

/*========================= Conexión con Thinger.io =========================*/

#define usuario "EstacionMeteo" //Nuestro usuario de Thinger.io
#define device_Id "Servidor_Meteo" //Poner el device_ID elegido en Thinger.io
#define device_credentials "A+aKTL!K2!Dv" //Poner nuestra device_credencials de Thinger.io

ThingerESP8266 thing(usuario, device_Id, device_credentials);

#define EMAIL_ENDPOINT "Prueba_IFTT"  //El endpoint se usa para integrar la plataforma thinger.io con servicios externos, en este caso, recibir notificación por email.

/*=========================  Variables para indicar si ya se realizo un aviso a la plataforma Thinger.io y no volver a hacerlo =========================*/
bool Aviso = true;
byte lux_Limite = 200;

int Luminosidad; //Para activar el endpoint y recibir un email al guardar el valor de "luminosidad"

/*-------------------------------FUNCIÓN PARA AVISOS THINGER.IO-------------------------------*/
void avisos_Thinger ()
{
  //Usamos la condición if para llamar el endpoint si la luminosidad supera al valor definido
  if (Luminosidad < lux_Limite) {
    Aviso = true;
    Serial.println("Avisos activados para luminosidad");
  }
  Serial.println (" ");
}
/*------------------------------------------FIN FUNCIÓN----------------------------------------*/

/*-------------------------------FUNCIÓN PARA TENER DOS DECIMALES EN THINGER.IO-------------------------------*/
//Para tener dos decimales en el bucket de Thinger, hay que convertir las variables con los resutados a String. El problema es con el cliente que no guarda los datos bien
//en la base de datos. (No usada) https://community.thinger.io/t/value-in-the-data-bucket-from-esp8266-is-too-much/3582/9

//Gestión de decimales de Thinger
    float round_to_dp(float in_value, int decimal_place)
    {
      float multiplier = powf(10.0f, decimal_place);
      in_value = roundf(in_value * multiplier) / multiplier;
      return in_value;
    }
/*------------------------------------------FIN FUNCIÓN----------------------------------------*/
  
/*/////////////////////////////////////////////////////////////////////////////////\\\\\\\\\\\\\\\\\\\\\\\\\\\\\\\\\\\\\\\\\\\\\\\\\\\\\\\\\\\\\\\\\\\\\\\\\\\\\\\\
////////////////////////////////////////////////////////////////===== Fin parámetros de Thinger.io =====\\\\\\\\\\\\\\\\\\\\\\\\\\\\\\\\\\\\\\\\\\\\\\\\\\\\\\\\\\\
/////////////////////////////////////////////////////////////////////////////////\\\\\\\\\\\\\\\\\\\\\\\\\\\\\\\\\\\\\\\\\\\\\\\\\\\\\\\\\\\\\\\\\\\\\\\\\\\\\\\\*/

/*================================================================================================================================================================*/

/*/////////////////////////////////////////////////////////////////////////////////\\\\\\\\\\\\\\\\\\\\\\\\\\\\\\\\\\\\\\\\\\\\\\\\\\\\\\\\\\\\\\\\\\\\\\\\\\\\\\\\
////////////////////////////////////////////////////////////////===== Parámetros de conexión WiFi =====\\\\\\\\\\\\\\\\\\\\\\\\\\\\\\\\\\\\\\\\\\\\\\\\\\\\\\\\\\\\
/////////////////////////////////////////////////////////////////////////////////\\\\\\\\\\\\\\\\\\\\\\\\\\\\\\\\\\\\\\\\\\\\\\\\\\\\\\\\\\\\\\\\\\\\\\\\\\\\\\\\*/

const char WiFi_ssid[] = "RedWifi";             //Nombre de red
const char WiFi_password[] = "KirguisT@N2035";  //Clave de red
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

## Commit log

2020-12-26 Rename servidor_sensores_PRUEBAS.ino to 2020_12_26_servidor_sensores_PRUEBAS.ino
    Añadida la señal RSSI out y ajustado el valor de la presión a hPa.
2020-12-26 Add files via upload
    Añadido sensor BME280 , señal RSSI y actualizado la API de Thinger.IO
2020-12-30 Rename servidor_sensores_PRUEBAS.ino to 2020_12_30_servidor_sensores_PRUEBAS.ino
    Añadido soporte OTA con la librería ESP8266_Utils_OTA.hpp (programarfacil.com)
2021-02-03 Add files via upload
    Añadida la veleta y el anemómetro. Ordenado el código.
2021-02-07 Rename servidor_sensores_PRUEBAS.ino to 2021_02_07_servidor_sensores_PRUEBAS.ino
    Añadido el pluviómetro con el promedio de lluvia en una hora y en 24 horas. Actualmente en el código es 6* 10010 para 1h y 6 * 3 * 10010 para 24h.
2021-02-07 Add files via upload
    Añadido el pluviómetro, la veleta y el anemómetro a la BD. Actualizado el php.
